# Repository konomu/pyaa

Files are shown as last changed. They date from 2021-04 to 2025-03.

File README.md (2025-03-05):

# Introducing pyaa!
A thirty key steno keyboard powered by QMK firmware and Plover.

## How do I build it?
To build pyaa, all you need is the following:
* PCB (two halves)
* 30 Kailh Choc switches (PG1350)
* 2 Pro Micros (or its derivatives)
  * **Important:** The Pro Micro's USB must face towards the board on both halves.
* 2 TRRS jacks (MJ-4PP-9 or PJ-320A)
* TRRS cable
* and optionally, 2 reset switches (TVBP06)

Once you have finished building it, you must flash the firmware onto the keyboard with QMK.

## How do I use it?
pyaa is powered by QMK firmware and takes advantage of its stenography, combo, and direct pin implementations. Its firmware is available [here](https://github.com/konomu/qmk_firmware/tree/pyaa/keyboards/pyaa). It functions along with [Plover](https://github.com/openstenoproject/plover), a desktop application developed as a part of the [Open Steno Project](http://www.openstenoproject.org/). 

## About
There are many other steno keyboards out there, all of which allow you to input text at speeds upwards of 200 words per minute with the magic of Plover! (and of course, a bit of practice) In fact, pyaa is heavily inspired by Georgi, which was developed by g Heavy Industries' Jane Bernhardt and is available at [gboards](https://www.gboards.ca/product/georgi). Other options for steno keyboards can be found on [Plover's wiki](https://github.com/openstenoproject/plover/wiki/Supported-Hardware).

The PCB uses a direct pin matrix, where each key is connected to an I/O pin on the microcontroller and ground. This makes it so that soldering diodes onto the pcb is not necessary as with other keyboards, reducing cost slightly. N-key rollover functionality, which is crucial for stenography, is left intact.

## Images

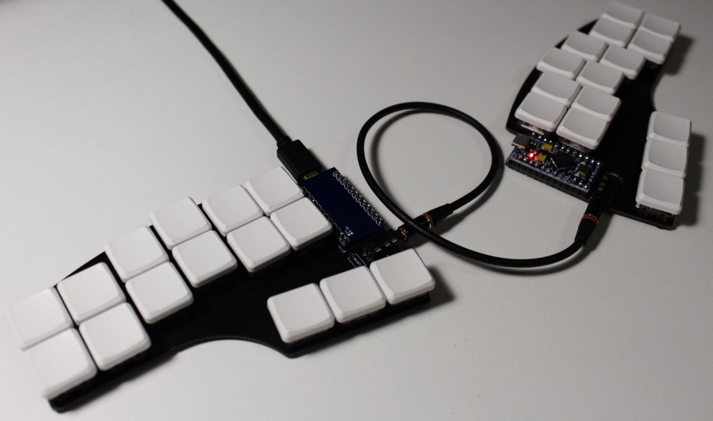
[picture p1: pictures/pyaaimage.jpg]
image of board pyaa


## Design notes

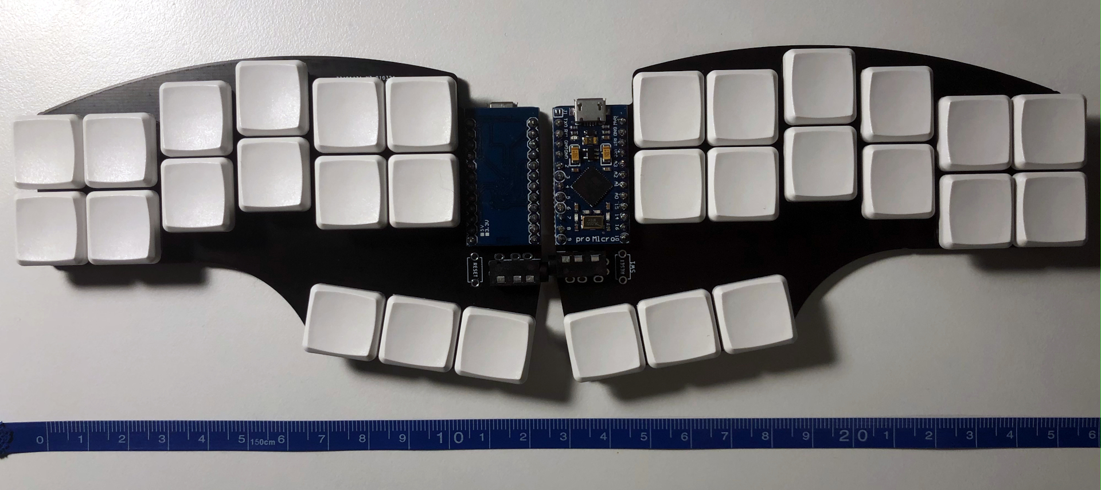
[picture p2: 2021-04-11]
pictures/scale.jpg

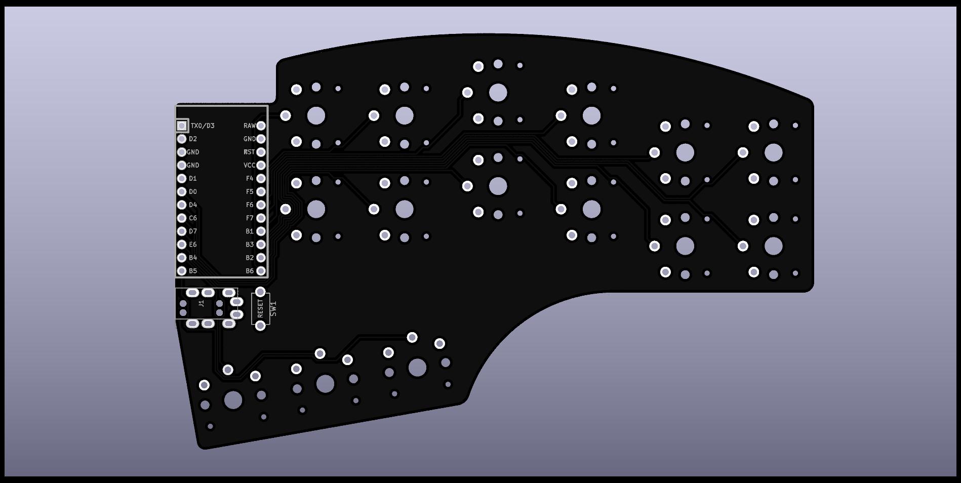
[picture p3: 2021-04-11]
pictures/pyaaboard.jpg

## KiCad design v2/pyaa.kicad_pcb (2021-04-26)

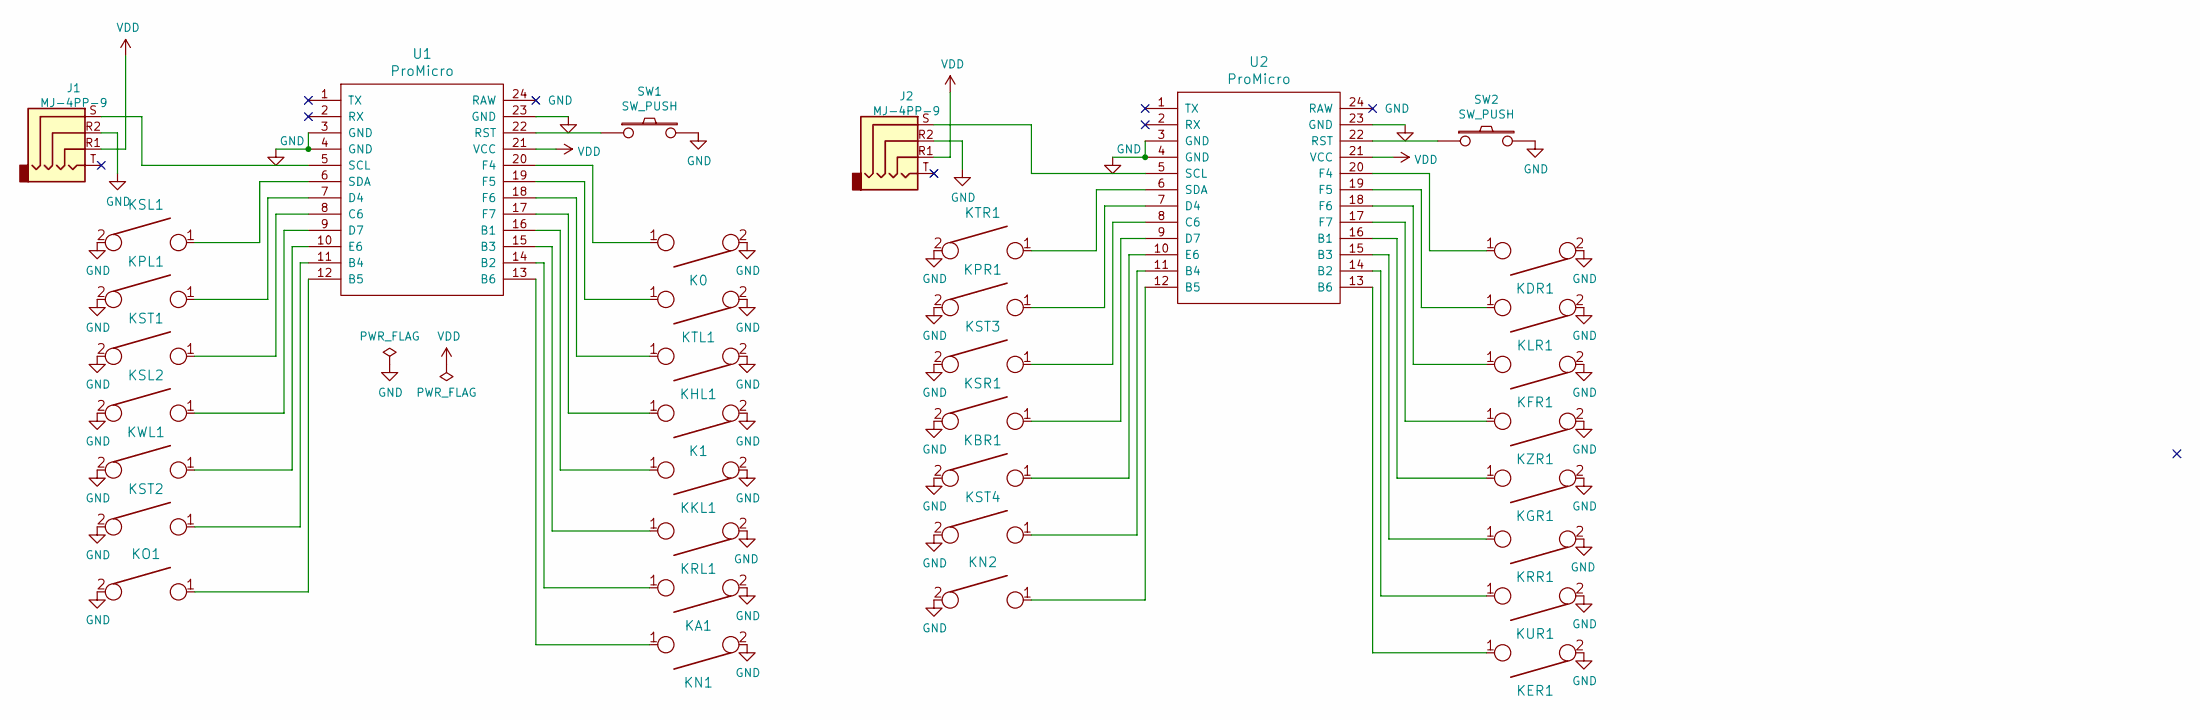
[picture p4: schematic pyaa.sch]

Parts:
J1, J2: MJ-4PP-9; TRRS-PJ-320A
K0, K1: KEYSW; Choc_PG1350_Choc_Spacing
KA1: KEYSW; Choc_PG1350_Choc_Spacing
KBR1: KEYSW; Choc_PG1350_Choc_Spacing
KDR1: KEYSW; Choc_PG1350_Choc_Spacing
KER1: KEYSW; Choc_PG1350_Choc_Spacing
KFR1: KEYSW; Choc_PG1350_Choc_Spacing
KGR1: KEYSW; Choc_PG1350_Choc_Spacing
KHL1: KEYSW; Choc_PG1350_Choc_Spacing
KKL1: KEYSW; Choc_PG1350_Choc_Spacing
KLR1: KEYSW; Choc_PG1350_Choc_Spacing
KN1, KN2: KEYSW; Choc_PG1350_Choc_Spacing
KO1: KEYSW; Choc_PG1350_Choc_Spacing
KPL1: KEYSW; Choc_PG1350_Choc_Spacing
KPR1: KEYSW; Choc_PG1350_Choc_Spacing
KRL1: KEYSW; Choc_PG1350_Choc_Spacing
KRR1: KEYSW; Choc_PG1350_Choc_Spacing
KSL1, KSL2: KEYSW; Choc_PG1350_Choc_Spacing
KSR1: KEYSW; Choc_PG1350_Choc_Spacing
KST1, KST2, KST3, KST4: KEYSW; Choc_PG1350_Choc_Spacing
KTL1: KEYSW; Choc_PG1350_Choc_Spacing
KTR1: KEYSW; Choc_PG1350_Choc_Spacing
KUR1: KEYSW; Choc_PG1350_Choc_Spacing
KWL1: KEYSW; Choc_PG1350_Choc_Spacing
KZR1: KEYSW; Choc_PG1350_Choc_Spacing
SW1, SW2: SW_PUSH; TACT_SWITCH_TVBP06
U1, U2: ProMicro; ProMicro_rev

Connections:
GND: J1.R2, J2.R2, K0.2, K1.2, KA1.2, KBR1.2, KDR1.2, KER1.2, KFR1.2, KGR1.2, KHL1.2, KKL1.2, KLR1.2, KN1.2, KN2.2, KO1.2, KPL1.2, KPR1.2, KRL1.2, KRR1.2, KSL1.2, KSL2.2, KSR1.2, KST1.2, KST2.2, KST3.2, KST4.2, KTL1.2, KTR1.2, KUR1.2, KWL1.2, KZR1.2, SW1.2, SW2.2, U1.3 (GND), U1.4 (GND), U1.23 (GND), U2.3 (GND), U2.4 (GND), U2.23 (GND)
unnamed: J1.S, U1.5 (SCL)
unnamed: J2.S, U2.5 (SCL)
unnamed: K0.1, U1.20 (F4)
unnamed: K1.1, U1.17 (F7)
unnamed: KA1.1, U1.14 (B2)
unnamed: KBR1.1, U2.10 (E6)
unnamed: KDR1.1, U2.20 (F4)
unnamed: KER1.1, U2.13 (B6)
unnamed: KFR1.1, U2.18 (F6)
unnamed: KGR1.1, U2.16 (B1)
unnamed: KHL1.1, U1.18 (F6)
unnamed: KKL1.1, U1.16 (B1)
unnamed: KLR1.1, U2.19 (F5)
unnamed: KN1.1, U1.13 (B6)
unnamed: KN2.1, U2.12 (B5)
unnamed: KO1.1, U1.12 (B5)
unnamed: KPL1.1, U1.7 (D4)
unnamed: KPR1.1, U2.7 (D4)
unnamed: KRL1.1, U1.15 (B3)
unnamed: KRR1.1, U2.15 (B3)
unnamed: KSL1.1, U1.6 (SDA)
unnamed: KSL2.1, U1.9 (D7)
unnamed: KSR1.1, U2.9 (D7)
unnamed: KST1.1, U1.8 (C6)
unnamed: KST2.1, U1.11 (B4)
unnamed: KST3.1, U2.8 (C6)
unnamed: KST4.1, U2.11 (B4)
unnamed: KTL1.1, U1.19 (F5)
unnamed: KTR1.1, U2.6 (SDA)
unnamed: KUR1.1, U2.14 (B2)
unnamed: KWL1.1, U1.10 (E6)
unnamed: KZR1.1, U2.17 (F7)
unnamed: SW1.1, U1.22 (RST)
unnamed: SW2.1, U2.22 (RST)
VDD: J1.R1, J2.R1, U1.21 (VCC), U2.21 (VCC)

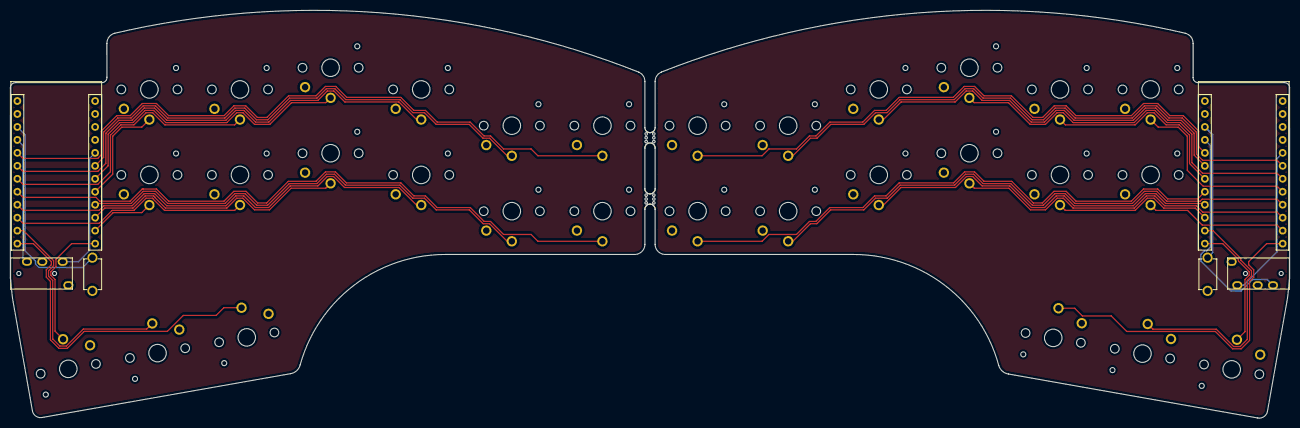
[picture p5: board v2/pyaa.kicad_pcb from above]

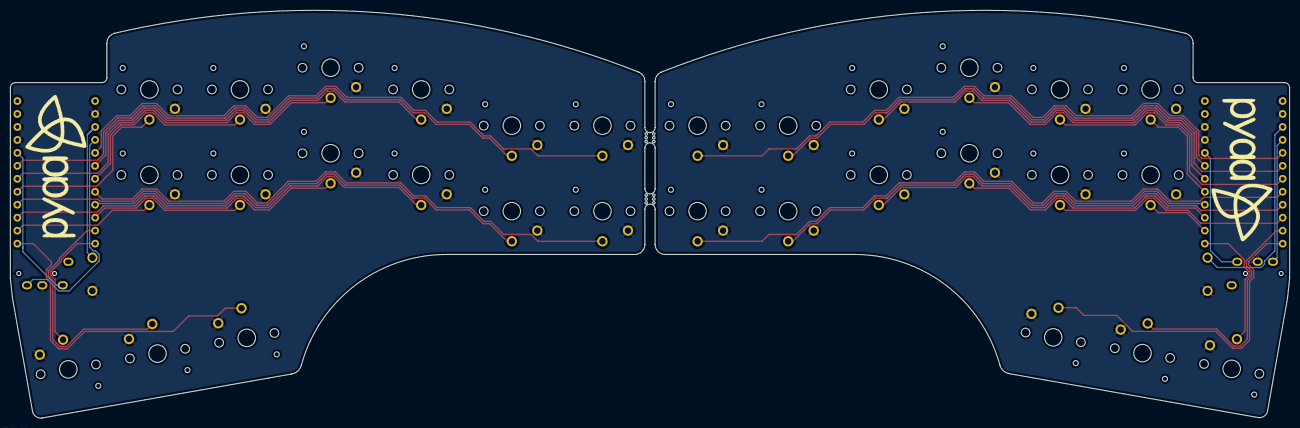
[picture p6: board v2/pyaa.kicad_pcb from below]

Board: 2 copper layers, 250.6 x 79.9 mm, 38 parts (2 on the bottom side), 36 nets.

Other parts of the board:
mouse-bite-2mm-slot, mouse-bite-2mm-slot#2: VAL**; mouse-bite-2mm-slot

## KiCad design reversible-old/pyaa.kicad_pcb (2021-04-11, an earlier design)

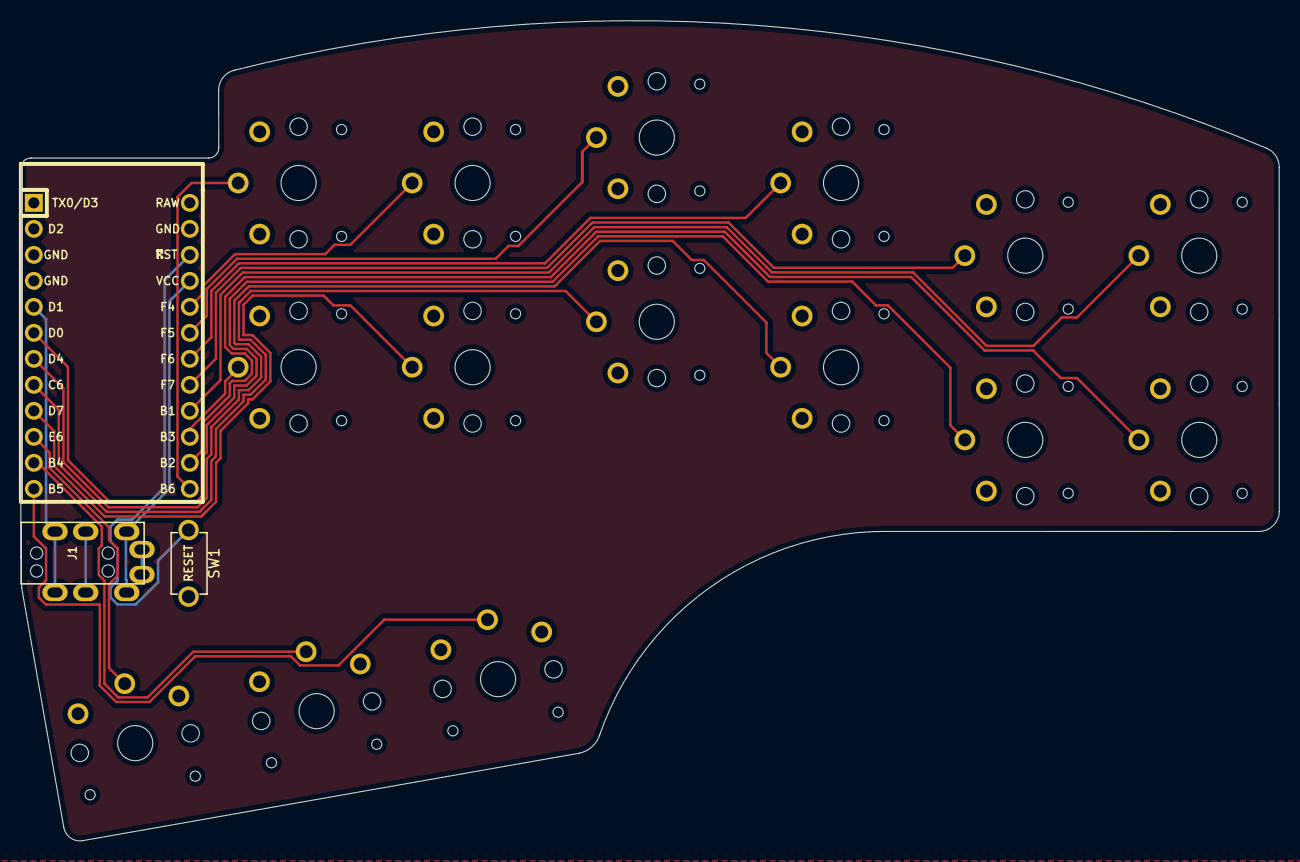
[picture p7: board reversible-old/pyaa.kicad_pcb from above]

Board: 2 copper layers, 123.0 x 80.1 mm, 18 parts (0 on the bottom side), 19 nets.

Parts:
J1: MJ-4PP-9; MJ-4PP-9_rev2
K0, K1: KEYSW; Choc_PG1350_Choc_Spacing_Reversible
KA1: KEYSW; Choc_PG1350_Choc_Spacing_Reversible
KHL1: KEYSW; Choc_PG1350_Choc_Spacing_Reversible
KKL1: KEYSW; Choc_PG1350_Choc_Spacing_Reversible
KN1: KEYSW; Choc_PG1350_Choc_Spacing_Reversible
KO1: KEYSW; Choc_PG1350_Choc_Spacing_Reversible
KPL1: KEYSW; Choc_PG1350_Choc_Spacing_Reversible
KRL1: KEYSW; Choc_PG1350_Choc_Spacing_Reversible
KS1, KS2: KEYSW; Choc_PG1350_Choc_Spacing_Reversible
KST1, KST2: KEYSW; Choc_PG1350_Choc_Spacing_Reversible
KTL1: KEYSW; Choc_PG1350_Choc_Spacing_Reversible
KWL1: KEYSW; Choc_PG1350_Choc_Spacing_Reversible
SW1: SW_PUSH; TACT_SWITCH_TVBP06
U1: ProMicro; ArduinoProMicro

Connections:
GND: J1.C, K0.2, K1.2, KA1.2, KHL1.2, KKL1.2, KN1.2, KO1.2, KPL1.2, KRL1.2, KS1.2, KS2.2, KST1.2, KST2.2, KTL1.2, KWL1.2, SW1.2, U1.3, U1.4, U1.23
unnamed: J1.B, U1.5
unnamed: K0.1, U1.16
unnamed: K1.1, U1.14
unnamed: KA1.1, U1.11
unnamed: KHL1.1, U1.20
unnamed: KKL1.1, U1.7
unnamed: KN1.1, U1.12
unnamed: KO1.1, U1.10
unnamed: KPL1.1, U1.19
unnamed: KRL1.1, U1.9
unnamed: KS1.1, U1.17
unnamed: KS2.1, U1.6
unnamed: KST1.1, U1.13
unnamed: KST2.1, U1.15
unnamed: KTL1.1, U1.18
unnamed: KWL1.1, U1.8
unnamed: SW1.1, U1.22
VDD: J1.D, U1.21

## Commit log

2021-04-11 Added project files
    [pyaa.kicad_pcb, pyaa.sch]
2021-04-11 Gerber files
    [pyaa-B_Cu.gbl, pyaa-B_Mask.gbs, pyaa-B_Paste.gbp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]
2021-04-26 update files
    [pyaa-B_Cu.gbl, pyaa-B_Mask.gbs, pyaa-B_Paste.gbp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]
